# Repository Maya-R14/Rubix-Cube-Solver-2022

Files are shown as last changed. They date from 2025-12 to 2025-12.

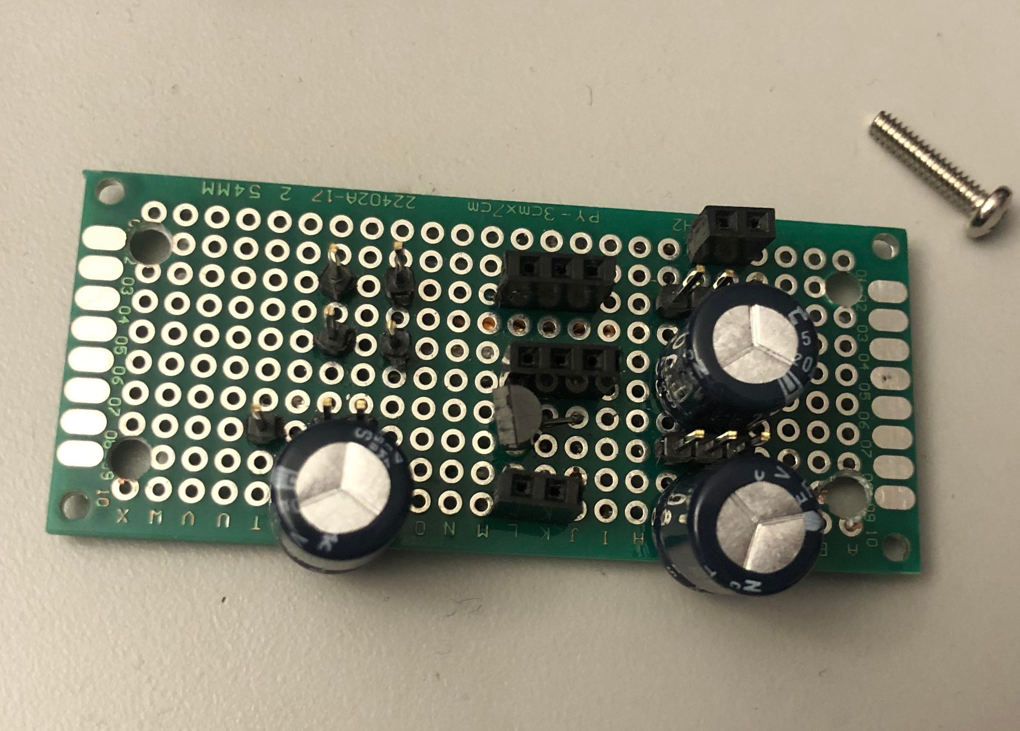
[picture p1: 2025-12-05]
Board and Components/Pinout Board.jpg

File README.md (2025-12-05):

# Rubix-Cube-Solver-2022
## MEDIA 
  Videos seem to be too large for Gethub.
- https://youtube.com/shorts/mSMcaVYMW5o?feature=share
- https://youtube.com/shorts/OSVltd1bibA?feature=share
## Features
- Servo motor–driven arms to manipulate the cube
- Sensor-based color detection for all cube faces
- Algorithm to compute the optimal solution
- Fully automated solving process

## Hardware
- Servo motors for cube manipulation
- Camera module
- Rasberry Pi
- Custom frame to hold cube
- PCB, resistors, capacitors, wires

## Software / Tools
- 3D Modeling/Solidworks
- Soldering
- PuTTY
- Raspberry Pi

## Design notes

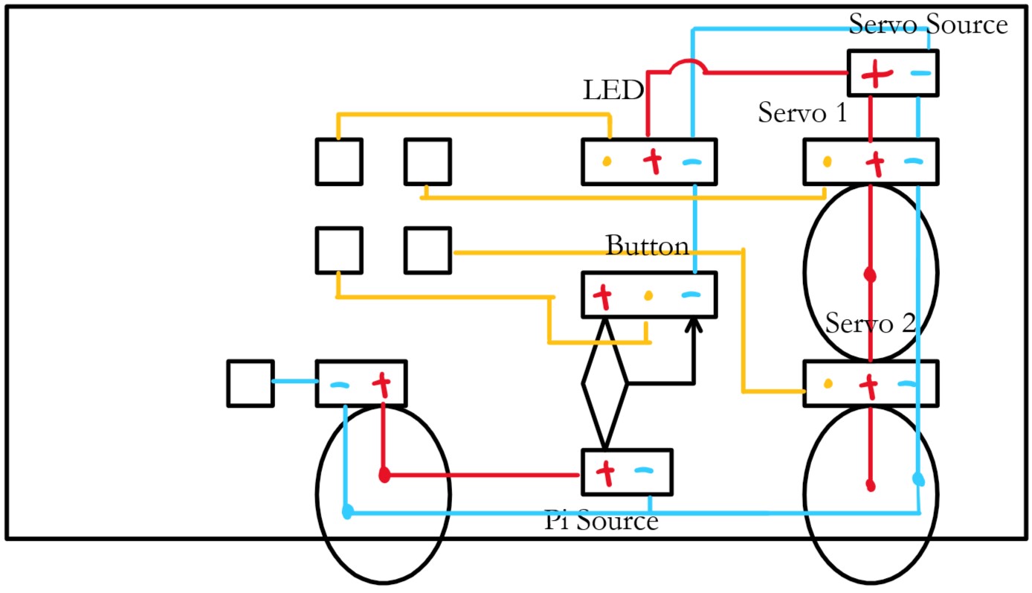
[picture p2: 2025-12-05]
Board and Components/Pinout Board Diagram.jpg

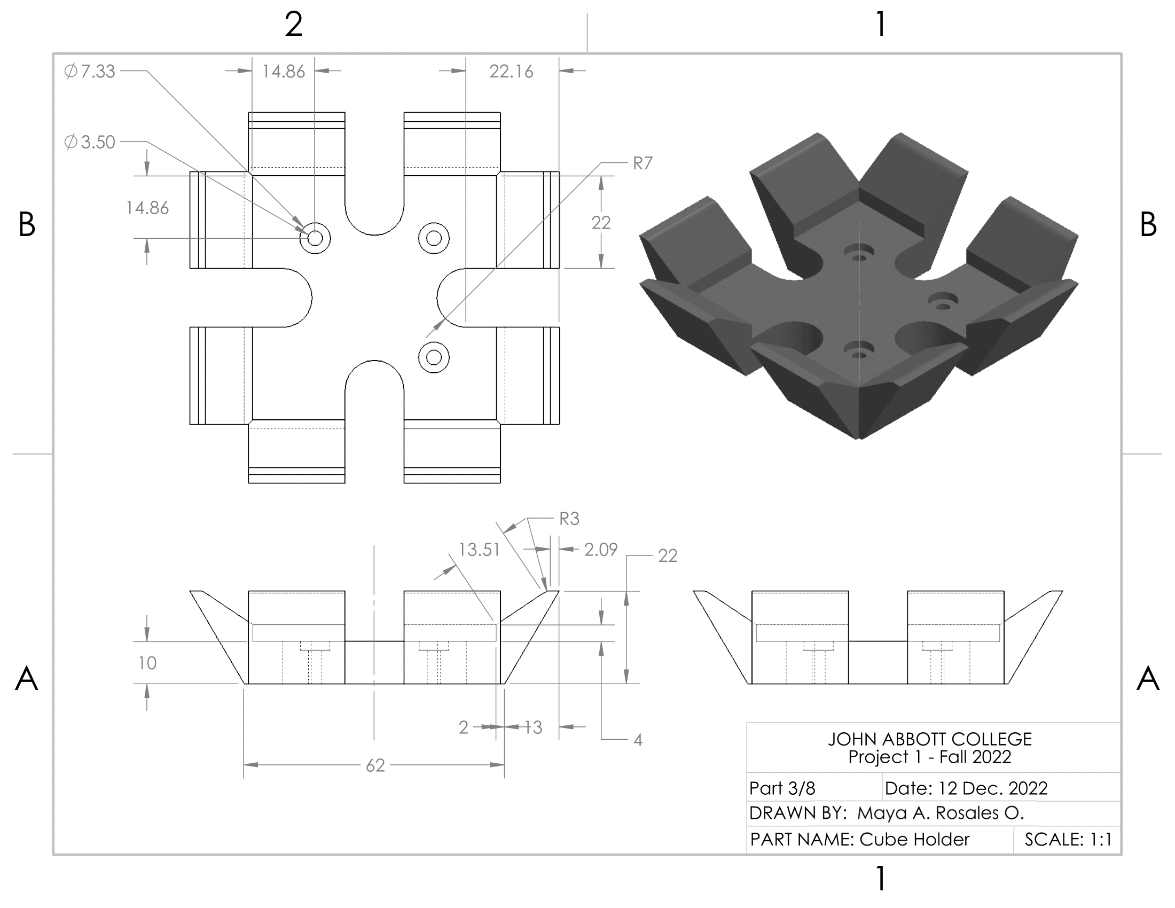
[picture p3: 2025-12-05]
3D Modeling/Technical Drawings/PNGs/Maya A. Rosales O._Solver_Technical Sheet-3.png

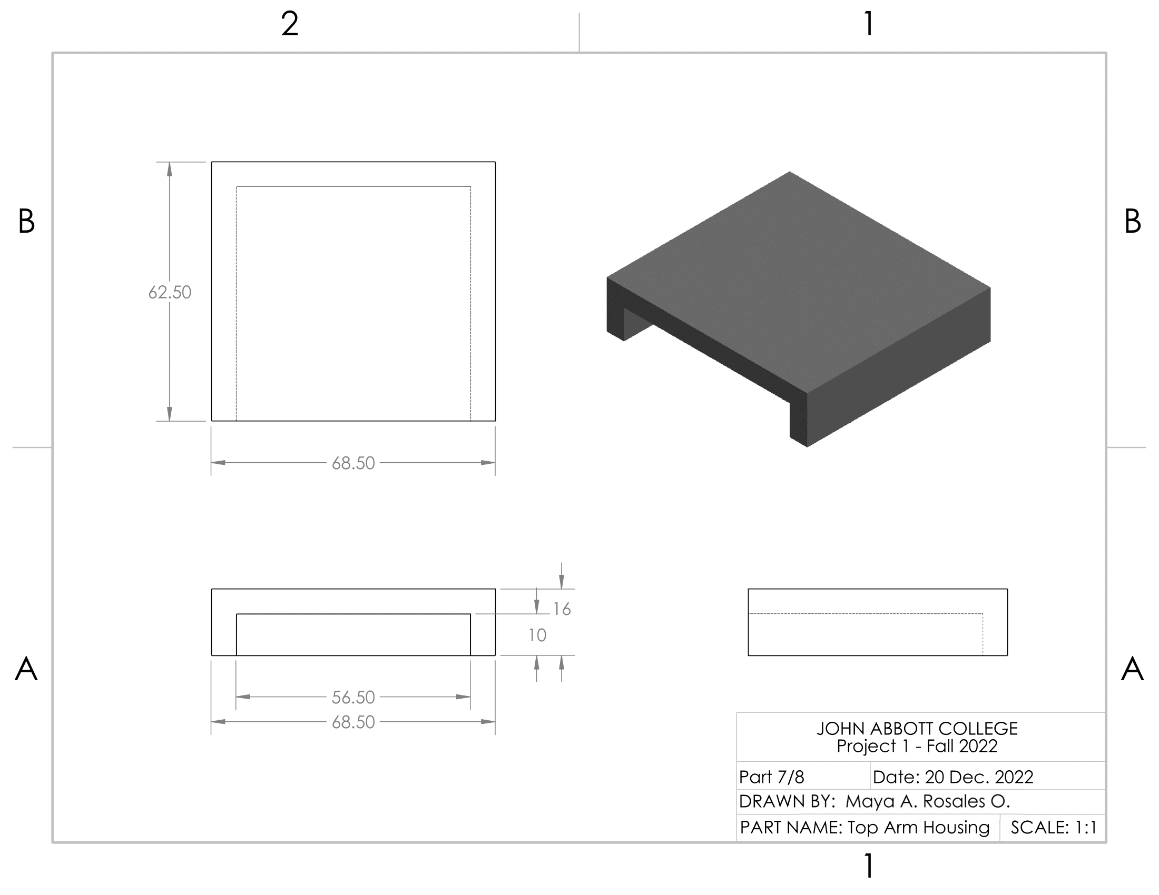
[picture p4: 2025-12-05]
3D Modeling/Technical Drawings/PNGs/Maya A. Rosales O._Solver_Technical Sheet-7.png

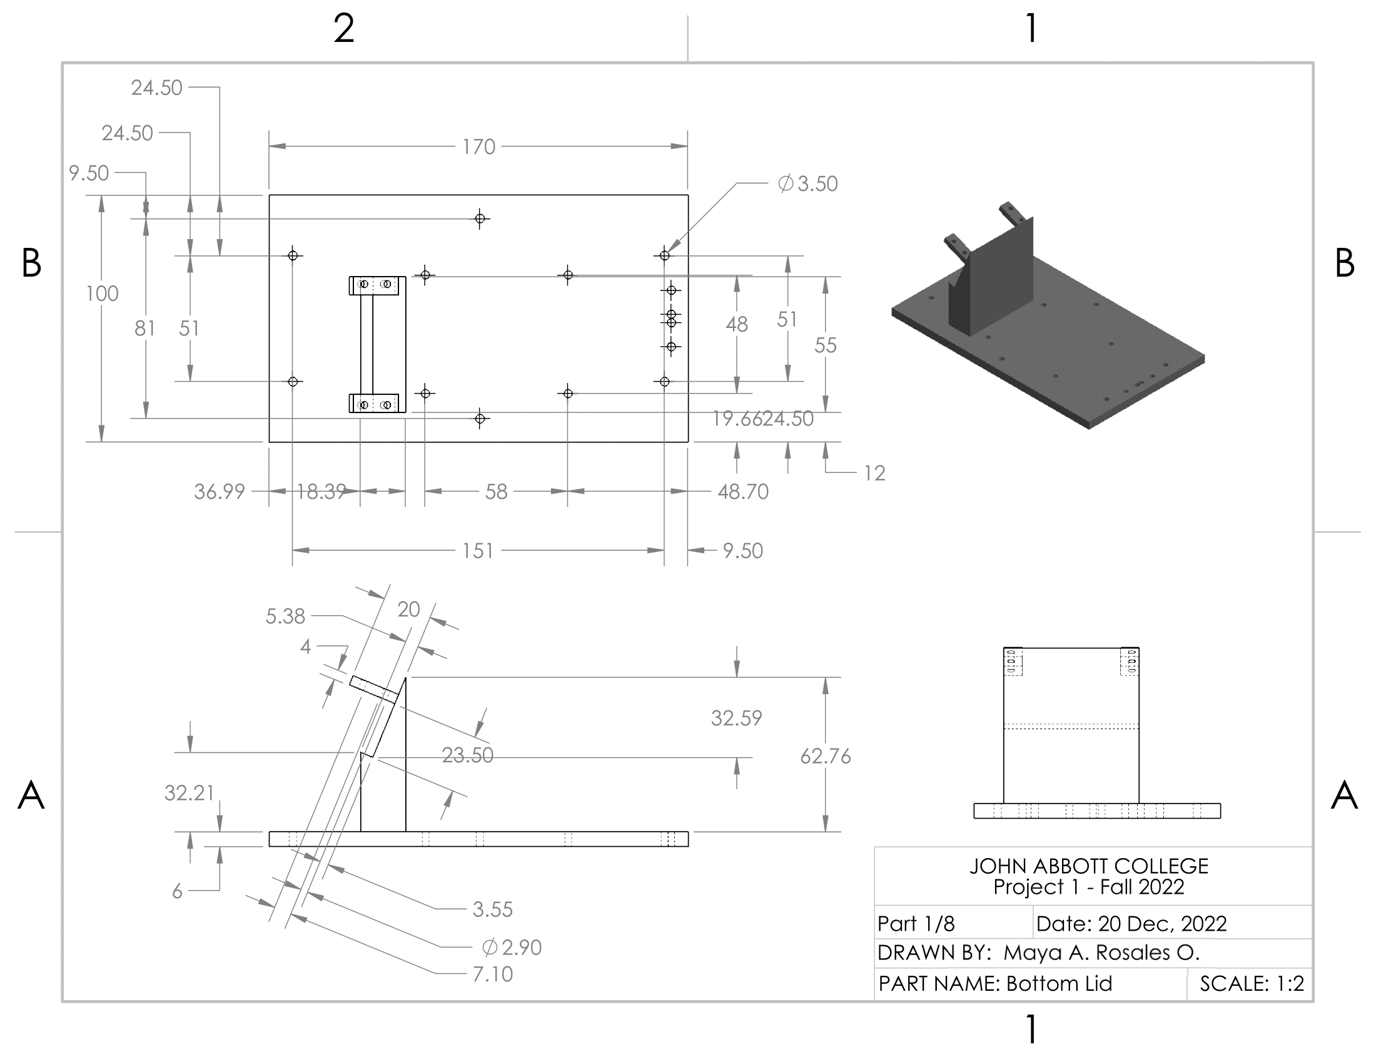
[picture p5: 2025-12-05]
3D Modeling/Technical Drawings/PNGs/Maya A. Rosales O._Solver_Technical Sheet-1.png

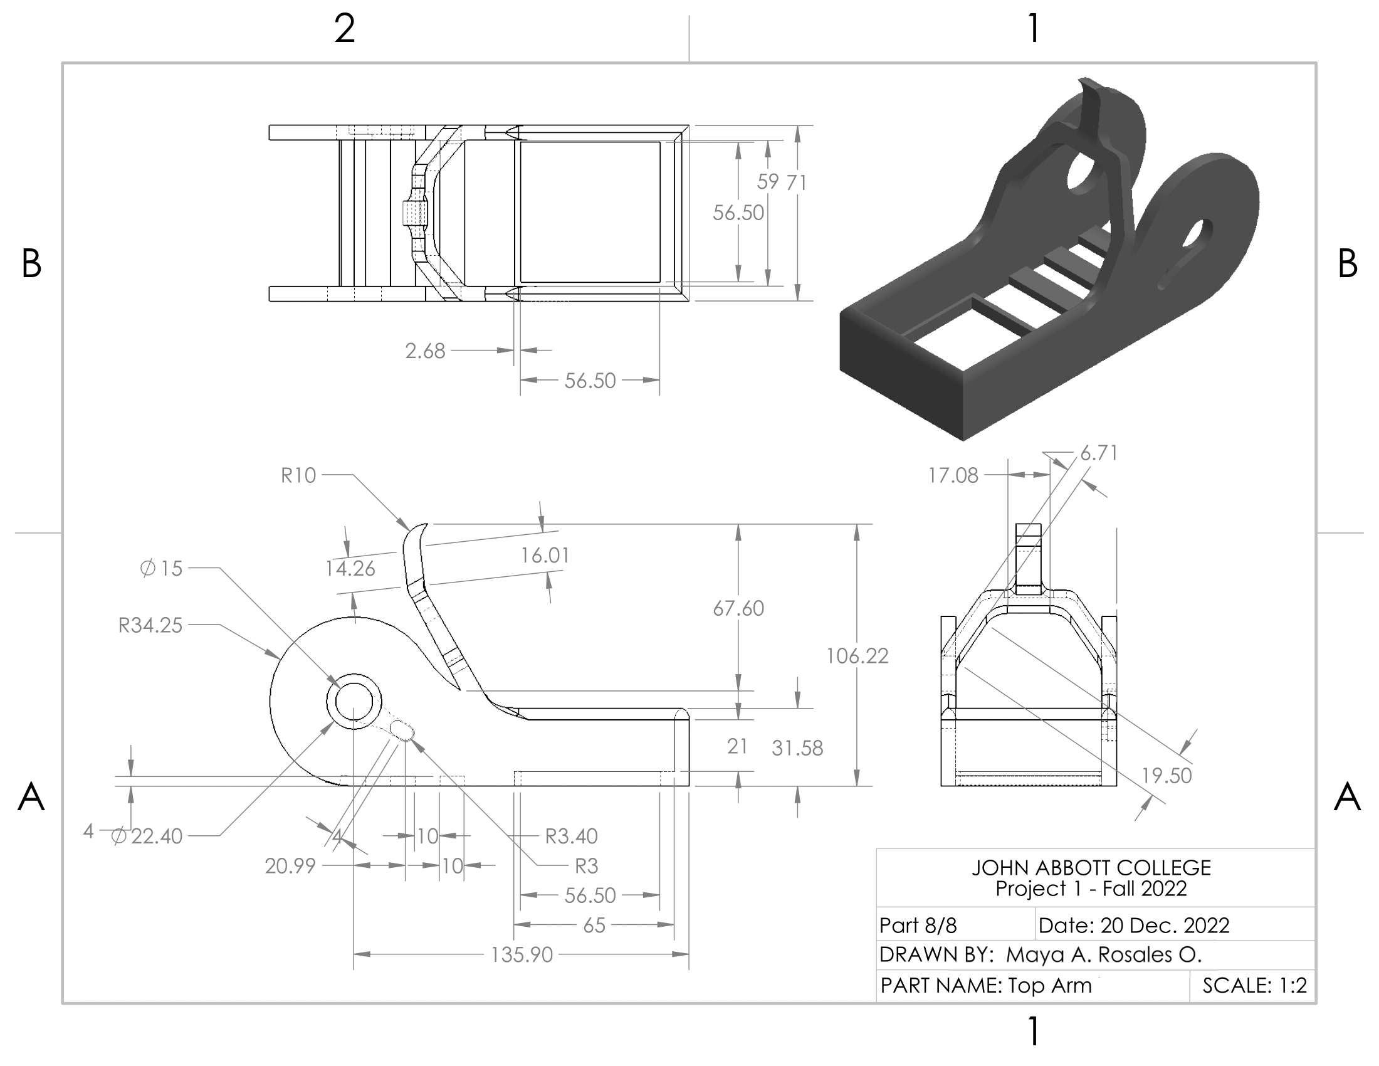
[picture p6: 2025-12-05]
3D Modeling/Technical Drawings/PNGs/Maya A. Rosales O._Solver_Technical Sheet-8.png

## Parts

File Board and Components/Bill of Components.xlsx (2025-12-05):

Amount | Item | Acquiring Method | Cost Per Unit | Total Cost
1 | Rasperry Pi 3B | Second Hand | $0.00 | $0.00
2 | 270 Degrees servo Motor | Bought at ABRA | $24.95 | $49.90
1 | Capacitive Touch Sensor | Bought at ABRA | $1.49 | $1.49
1 | 3W LED | Bought at ABRA | $3.37 | $3.37
2 | Micro USB breakout Board | Bought at ABRA | $1.68 | $3.36
1 | Pi Camera 1.3V | Bought at Amazon | $14.99 | $14.99
1 | FFC Cable | Bought at Amazon | $3.07 | $3.07
1 | LED Indicator | Bought at ABRA | $4.00 | $4.00
1 | L4931 Voltage Regulator | Bought at ABRA | $1.95 | $1.95
1 | 3x7 Printed Circuit | Bought at ABRA | $1.92 | $1.92
3 | Capacitors 35V, 220uF | Provided By JAC | $0.00 | $0.00
2 | Header Set | Bought at ABRA | $1.07 | $2.14
N/A | 3D Printing Material | Provided By JAC | $0.00 | $0.00
29 | 4-40 screws (various lengths) | Provided By JAC | $0.00 | $0.00
17 | 4-40 Bolts | Provided By JAC | $0.00 | $0.00
 |  |  | Total | $86.19
 |  |  | Total + Tax | $99.12

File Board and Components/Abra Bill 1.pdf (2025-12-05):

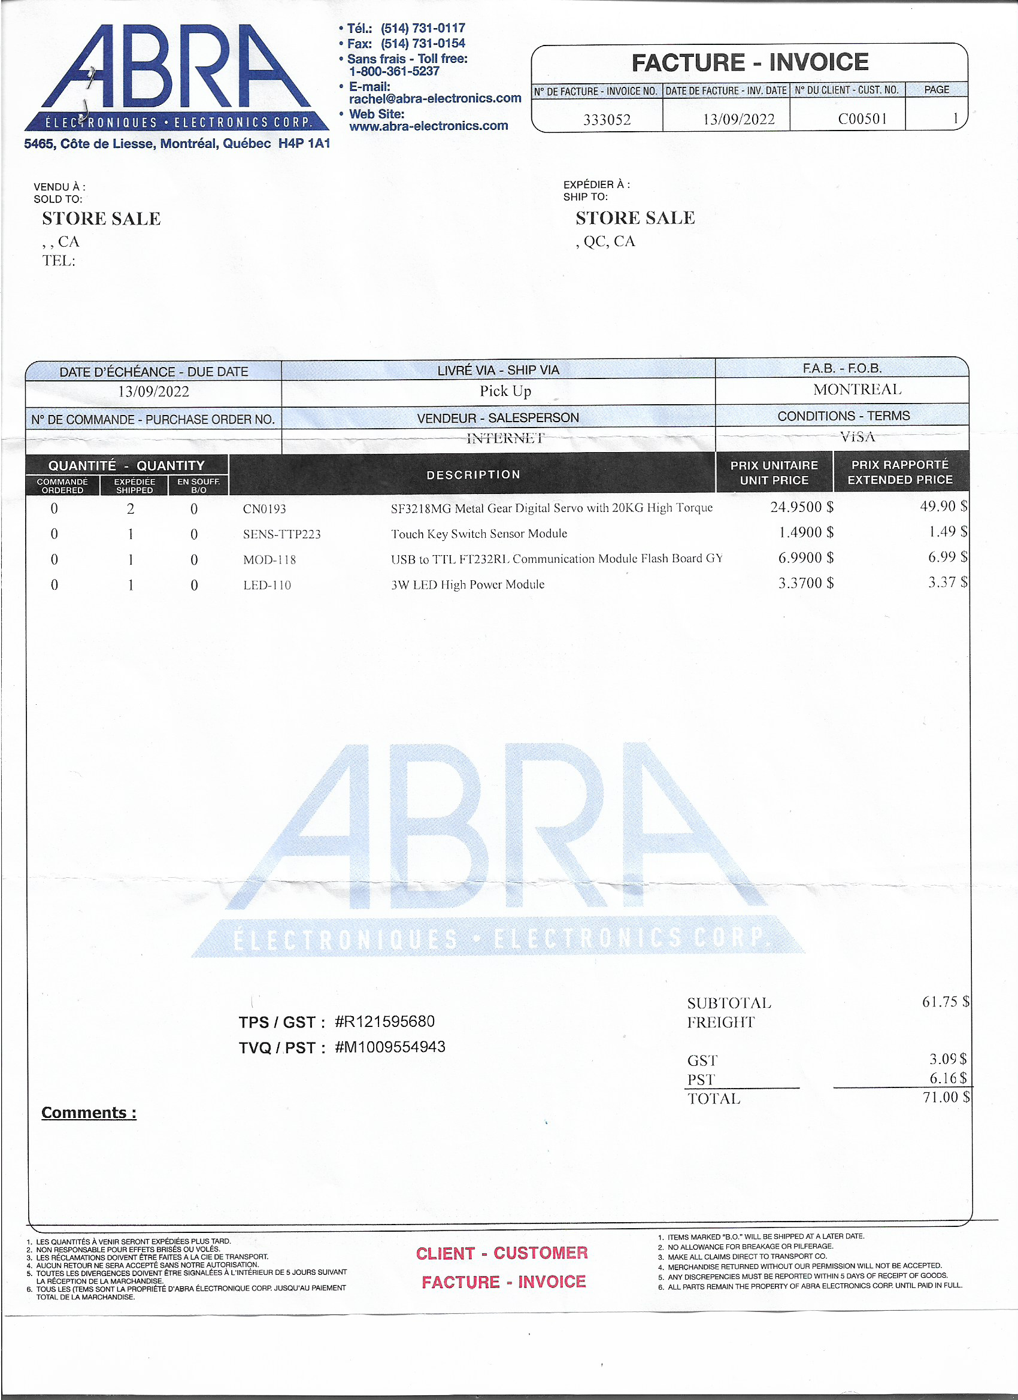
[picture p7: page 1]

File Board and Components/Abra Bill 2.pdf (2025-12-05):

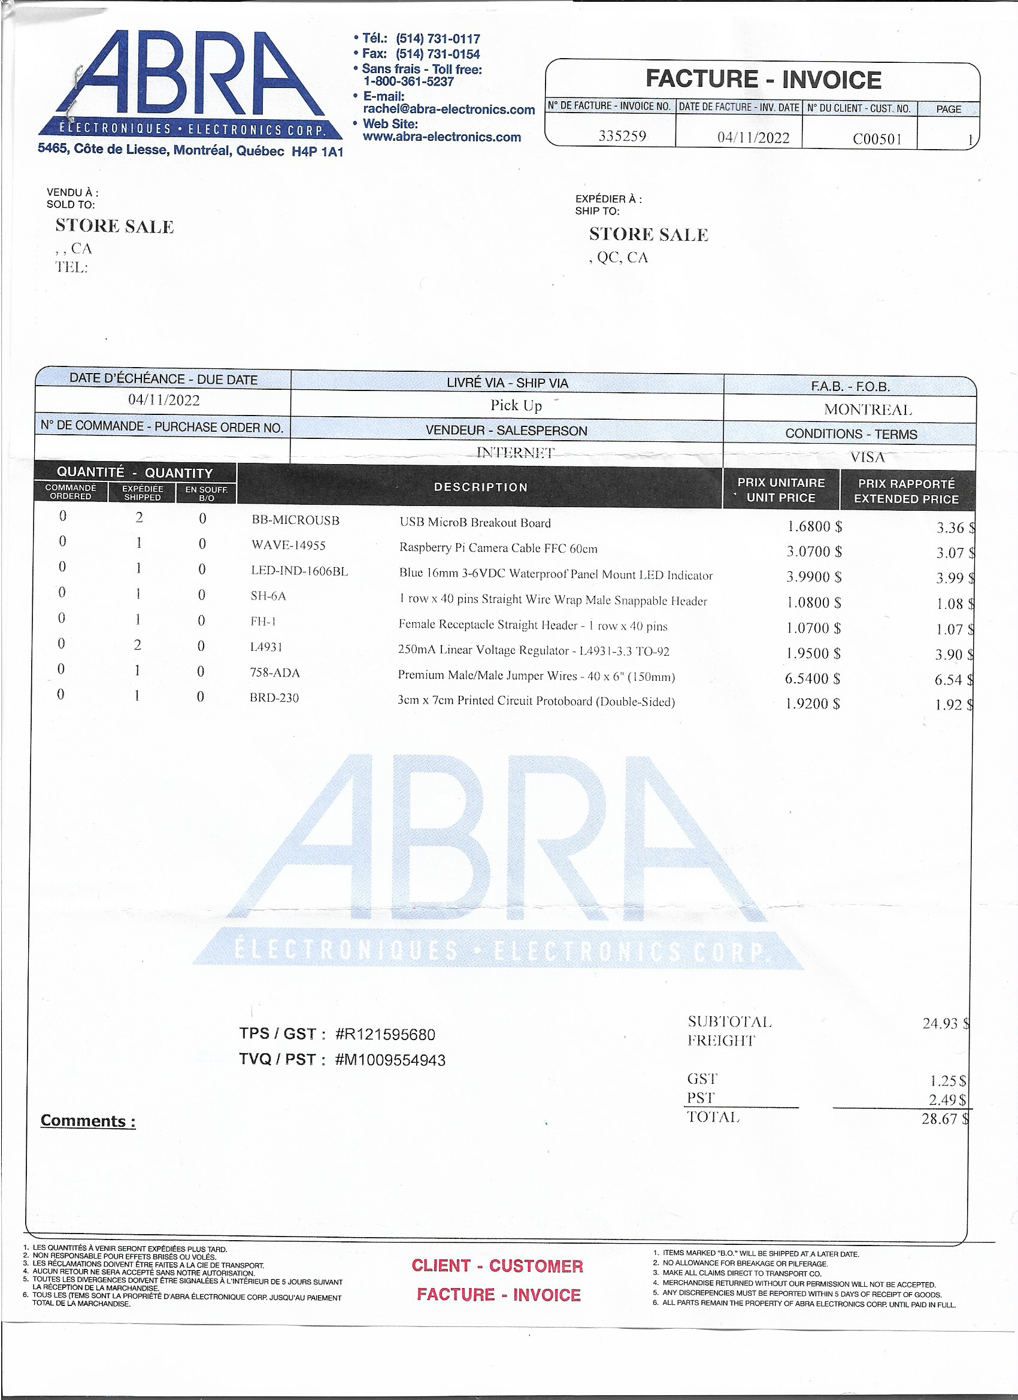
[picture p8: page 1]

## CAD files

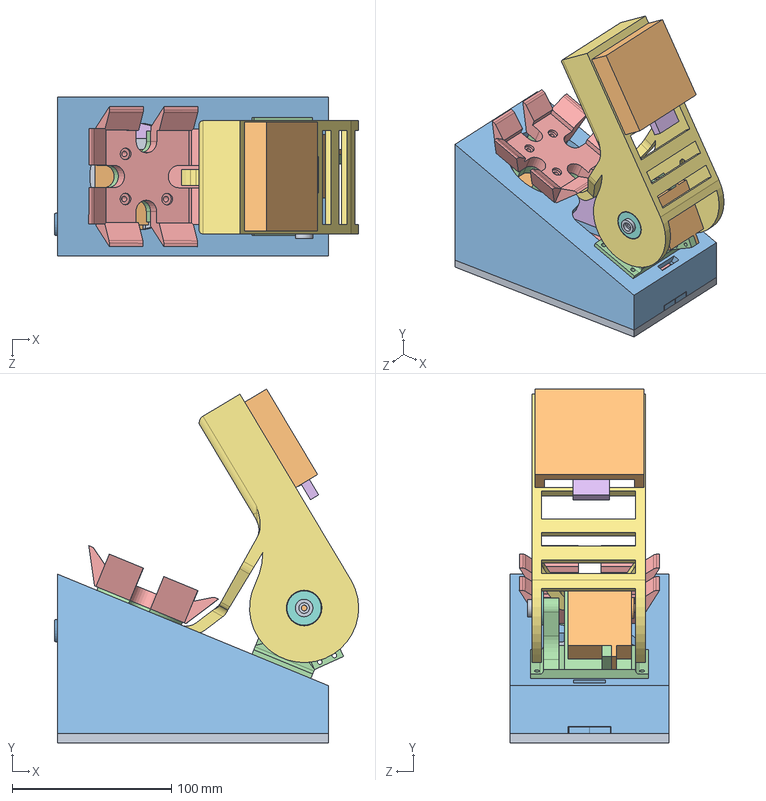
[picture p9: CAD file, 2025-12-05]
3D Modeling/Rubix Cube Solver Assembly.SLDASM
191.0 x 222.2 x 100.0 mm
Part - Bottom Lid
REFERENCE - Motor x 2
Part - Casing
Part - Hinge
REFERENCE - PI
REFERENCE - Connection Board
Part - Top Arm
REFERENCE - Ball Bearing
Part - Hinge - Screw
Part - Top Arm - Camera Housing
REFERENCE - Charging Board x 2
Part - Rotary Disk
Part - Cube Holder
REFERENCE - LED
REFERENCE - Pi Camera

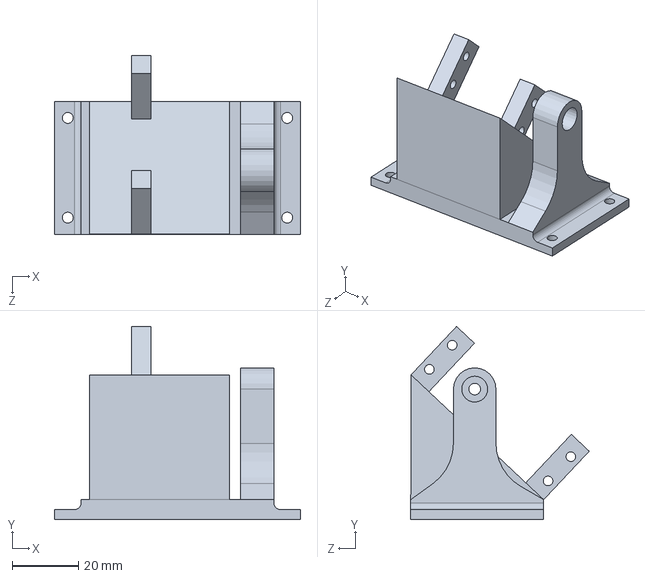
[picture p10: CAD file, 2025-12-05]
3D Modeling/Parts/Part - Hinge.SLDPRT
74.0 x 58.1 x 53.7 mm

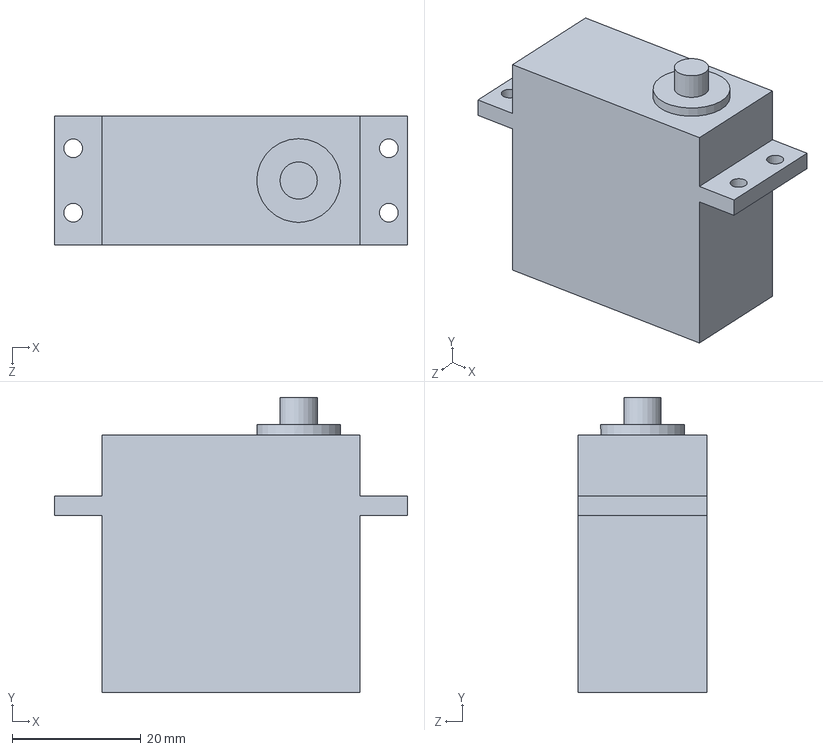
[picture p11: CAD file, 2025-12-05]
3D Modeling/References/REFERENCE - Motor.SLDPRT
54.8 x 45.8 x 20.0 mm

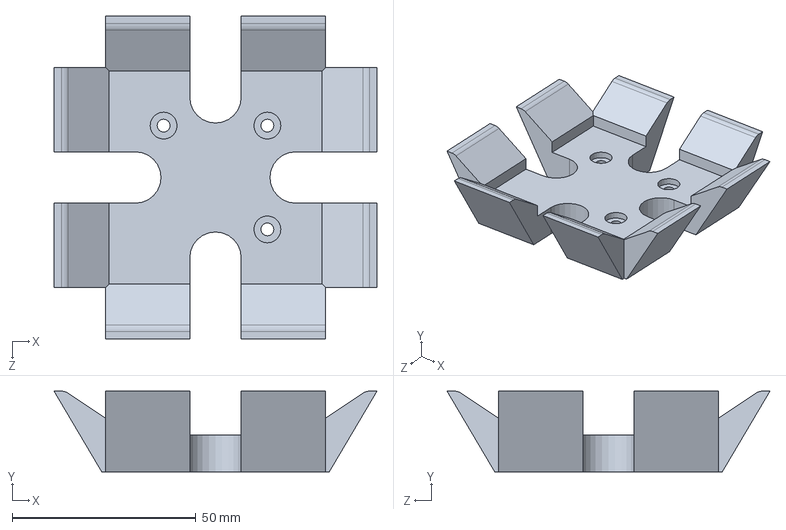
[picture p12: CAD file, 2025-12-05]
3D Modeling/Parts/Part - Cube Holder.SLDPRT
88.0 x 22.0 x 88.0 mm

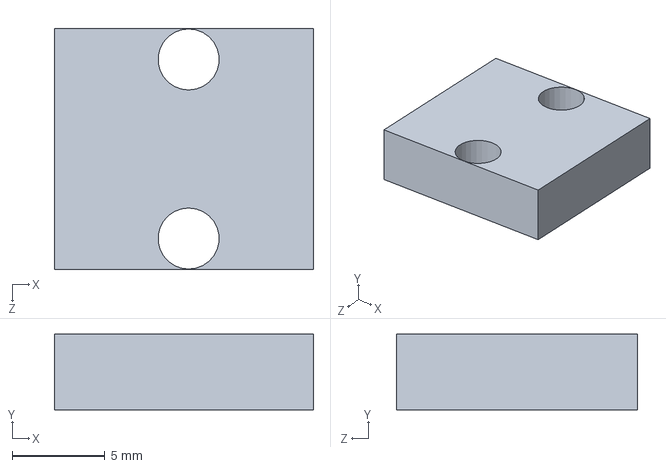
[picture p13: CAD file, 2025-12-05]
3D Modeling/References/REFERENCE - Charging Board.SLDPRT
14.0 x 4.10 x 13.0 mm

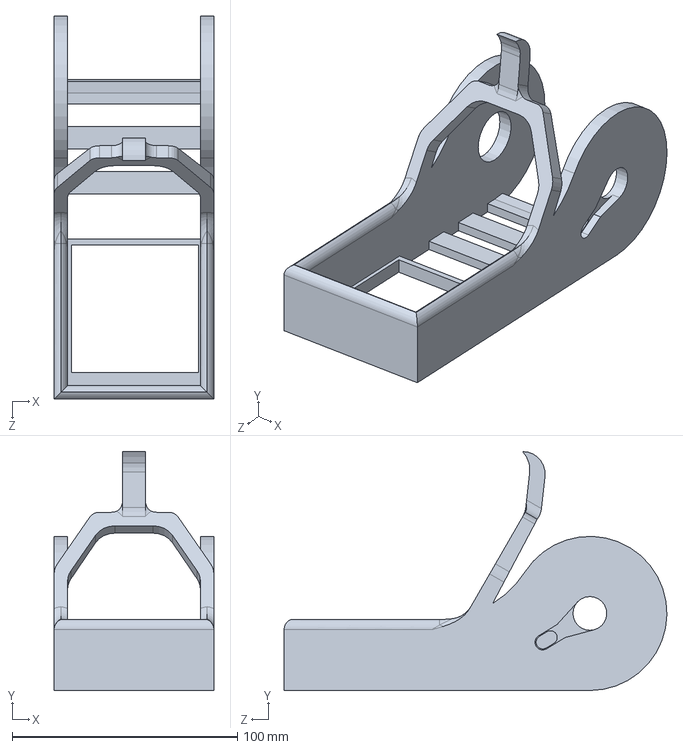
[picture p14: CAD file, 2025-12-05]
3D Modeling/Parts/Part - Top Arm.SLDPRT
71.0 x 106.2 x 170.1 mm

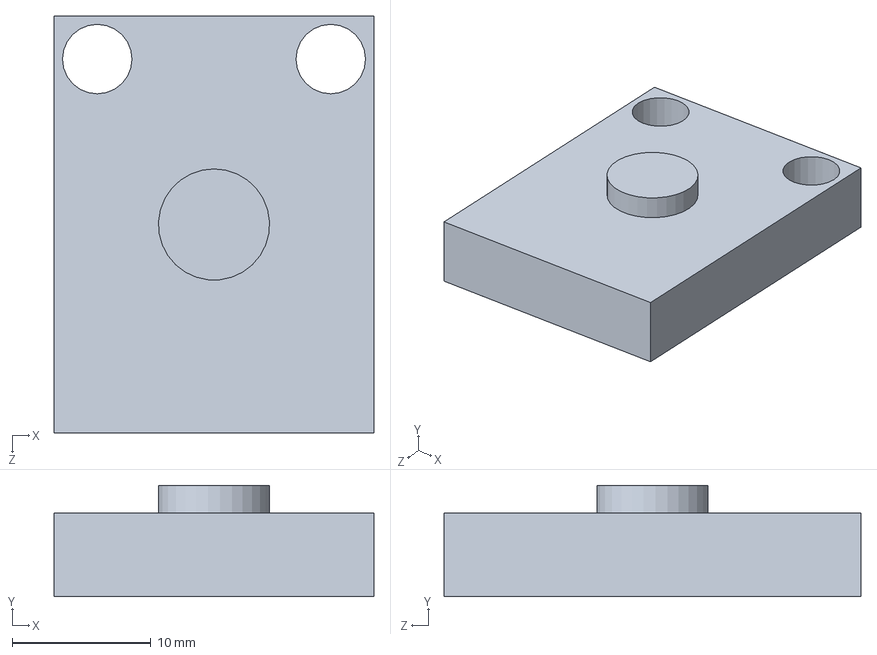
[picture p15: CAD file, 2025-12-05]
3D Modeling/References/REFERENCE - LED.SLDPRT
23.0 x 8.00 x 30.0 mm

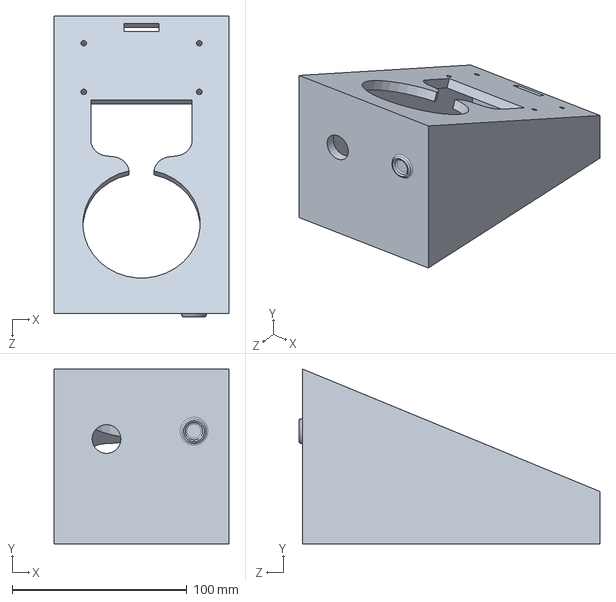
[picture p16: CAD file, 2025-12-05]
3D Modeling/Parts/Part - Casing.SLDPRT
100.0 x 100.0 x 172.0 mm

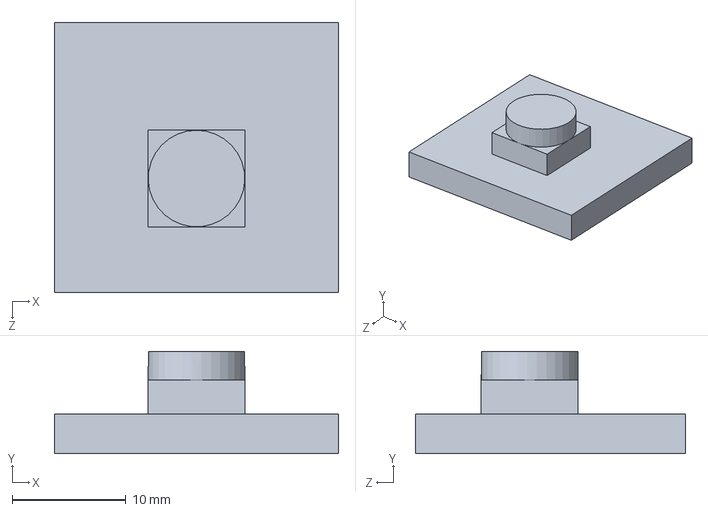
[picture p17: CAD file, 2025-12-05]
3D Modeling/References/REFERENCE - Pi Camera.SLDPRT
25.0 x 9.00 x 23.8 mm

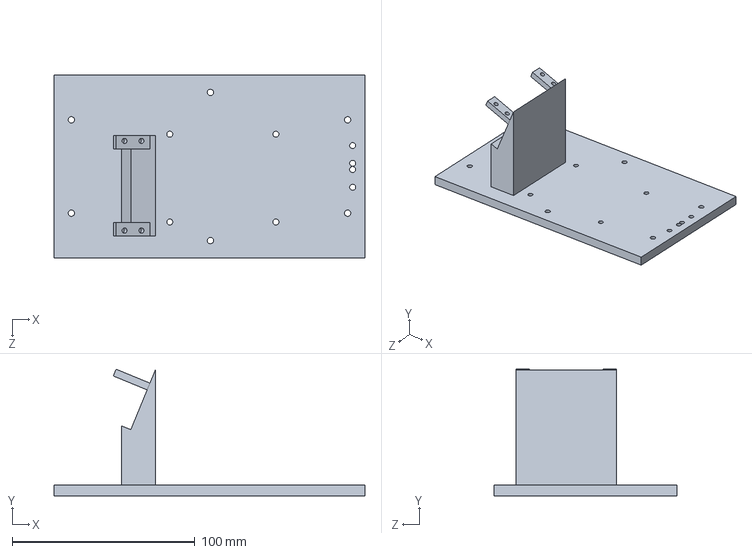
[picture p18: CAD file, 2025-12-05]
3D Modeling/Parts/Part - Bottom Lid.SLDPRT
170.0 x 69.2 x 100.0 mm

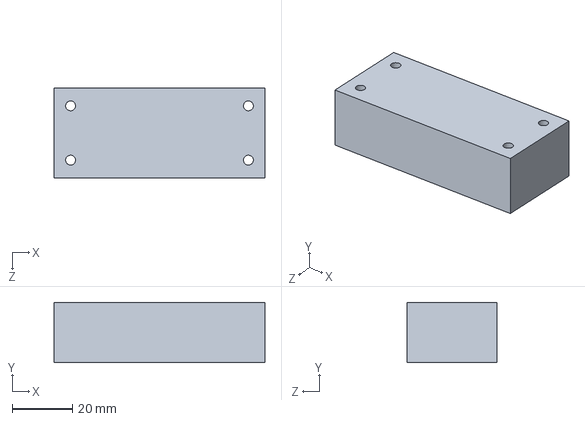
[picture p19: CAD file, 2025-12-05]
3D Modeling/References/REFERENCE - Connection Board.SLDPRT
70.0 x 20.0 x 30.0 mm

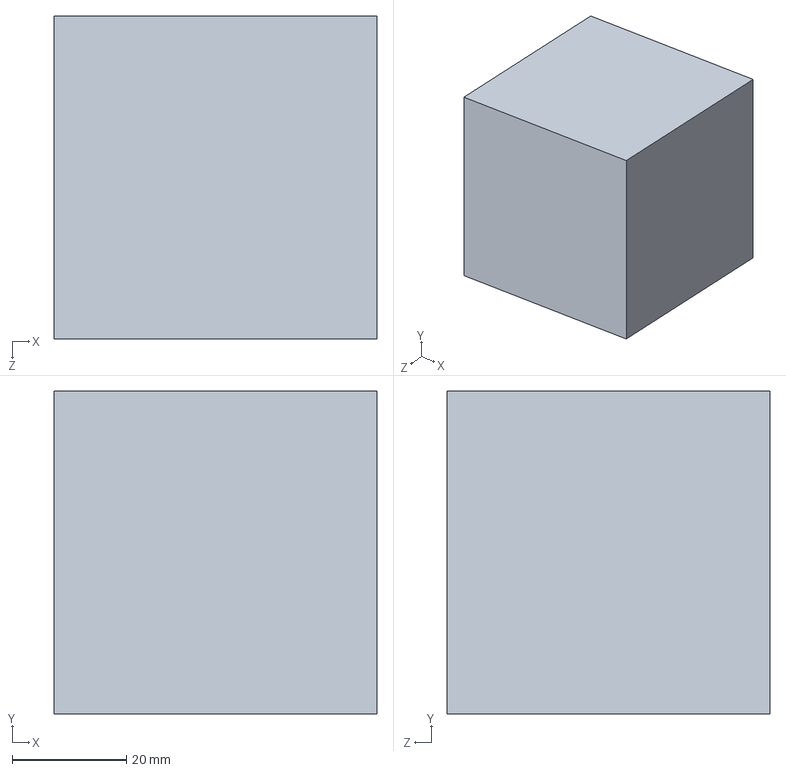
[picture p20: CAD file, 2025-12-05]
3D Modeling/References/REFERENCE - Rubix Cube.SLDPRT
56.5 x 56.5 x 56.5 mm

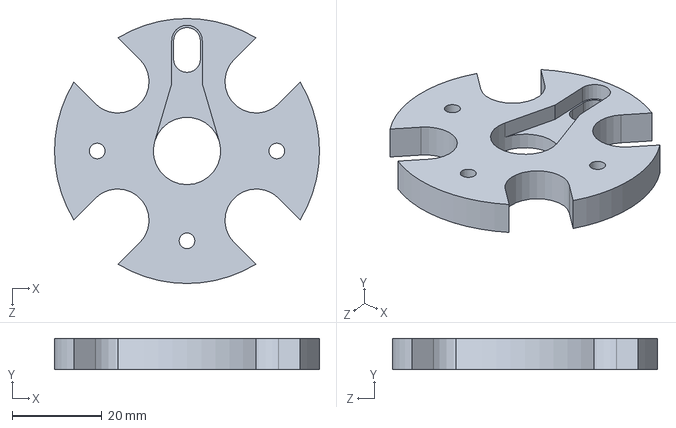
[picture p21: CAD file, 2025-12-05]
3D Modeling/Parts/Part - Rotary Disk.SLDPRT
59.0 x 7.00 x 59.0 mm

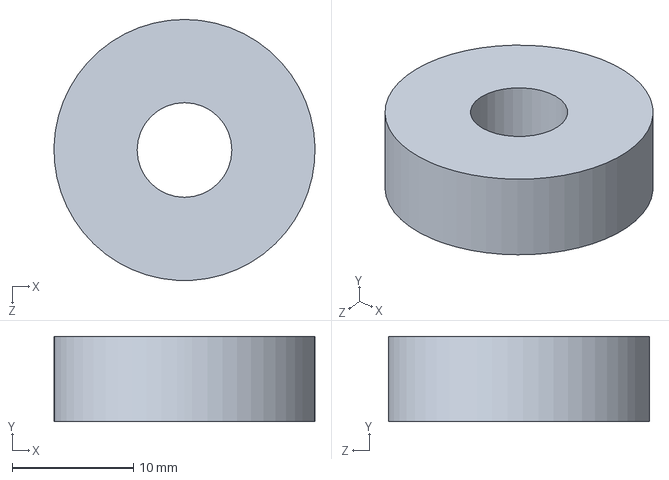
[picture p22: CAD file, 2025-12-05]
3D Modeling/References/REFERENCE - Ball Bearing.SLDPRT
21.5 x 7.00 x 21.5 mm

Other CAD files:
3D Modeling/Parts/Part - Top Arm - Camera Housing.SLDPRT
3D Modeling/References/REFERENCE - PI.SLDPRT
3D Modeling/Parts/Part - Hinge - Screw.SLDPRT
3D Modeling/STL Files (Printable)/Part - Bottom Lid.STL
3D Modeling/STL Files (Printable)/Part - Casing.STL
3D Modeling/STL Files (Printable)/Part - Cube Holder.STL
3D Modeling/STL Files (Printable)/Part - Hinge - Screw.STL
3D Modeling/STL Files (Printable)/Part - Hinge.STL
3D Modeling/STL Files (Printable)/Part - Rotary Disk.STL
3D Modeling/STL Files (Printable)/Part - Top Arm - Camera Housing.STL
3D Modeling/STL Files (Printable)/Part - Top Arm.STL
3D Modeling/Technical Drawings/Drawings/Drawing - Bottom Lid.SLDDRW
3D Modeling/Technical Drawings/Drawings/Drawing - Casing.SLDDRW
3D Modeling/Technical Drawings/Drawings/Drawing - Cube Holder.SLDDRW
3D Modeling/Technical Drawings/Drawings/Drawing - Hinge Screw.SLDDRW
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

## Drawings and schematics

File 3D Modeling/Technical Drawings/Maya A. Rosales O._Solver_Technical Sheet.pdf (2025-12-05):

B

B

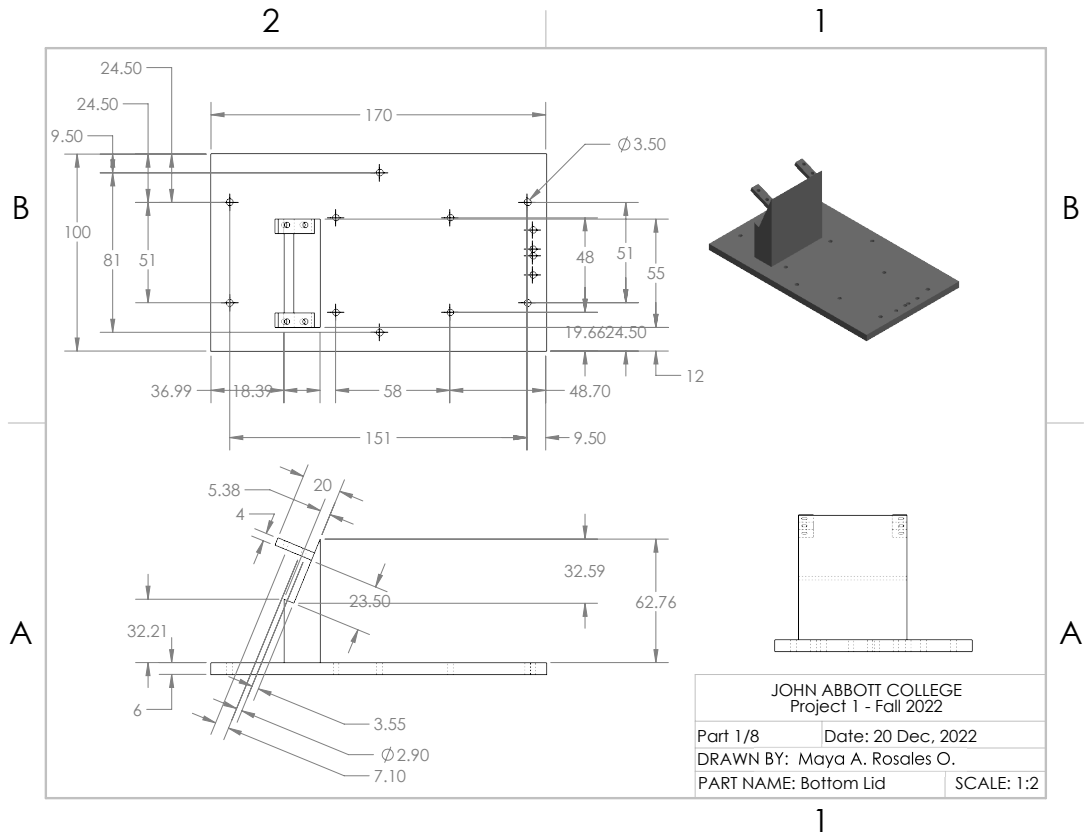
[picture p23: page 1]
Part 1/8; Date: 20 Dec, 2022; PART NAME: Bottom Lid; SCALE: 1:2

JOHN ABBOTT COLLEGE
Project 1 - Fall 2022

DRAWN BY: Marco A. Rosales O.

B

B

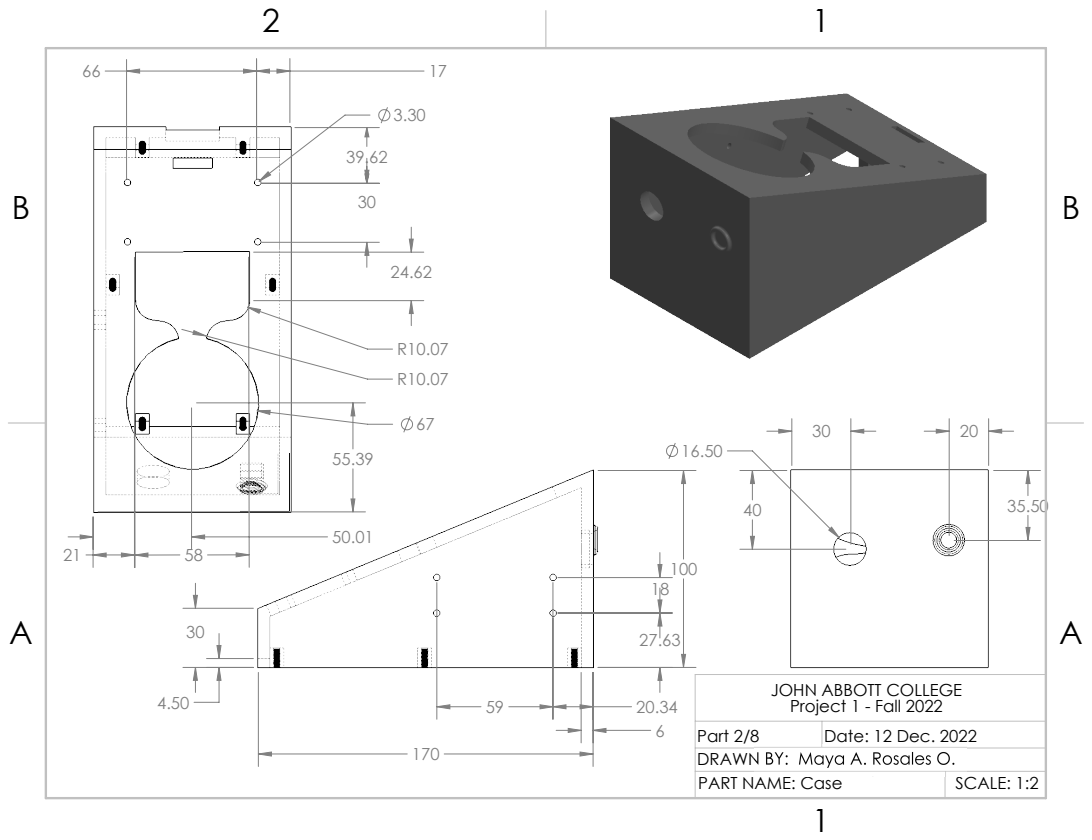
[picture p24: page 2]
Part 2/8; Date: 12 Dec. 2022; DRAWN BY: Marco A. Rosales O.; PART NAME: Case; SCALE: 1:2

JOHN ABBOTT COLLEGE
Project 1 - Fall 2022

B

B

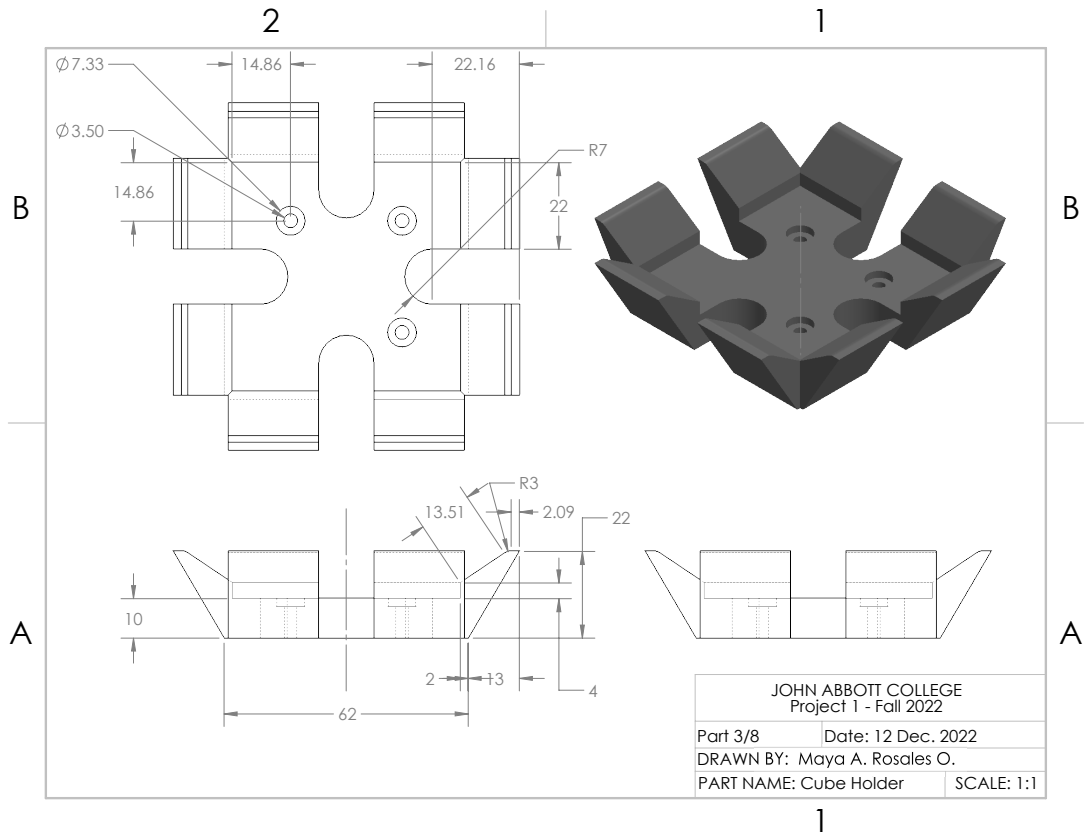
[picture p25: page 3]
Part 3/8; Date: 12 Dec. 2022; PART NAME: Cube Holder; SCALE: 1:1

JOHN ABBOTT COLLEGE
Project 1 - Fall 2022

DRAWN BY: Marco A. Rosales O.

B

B

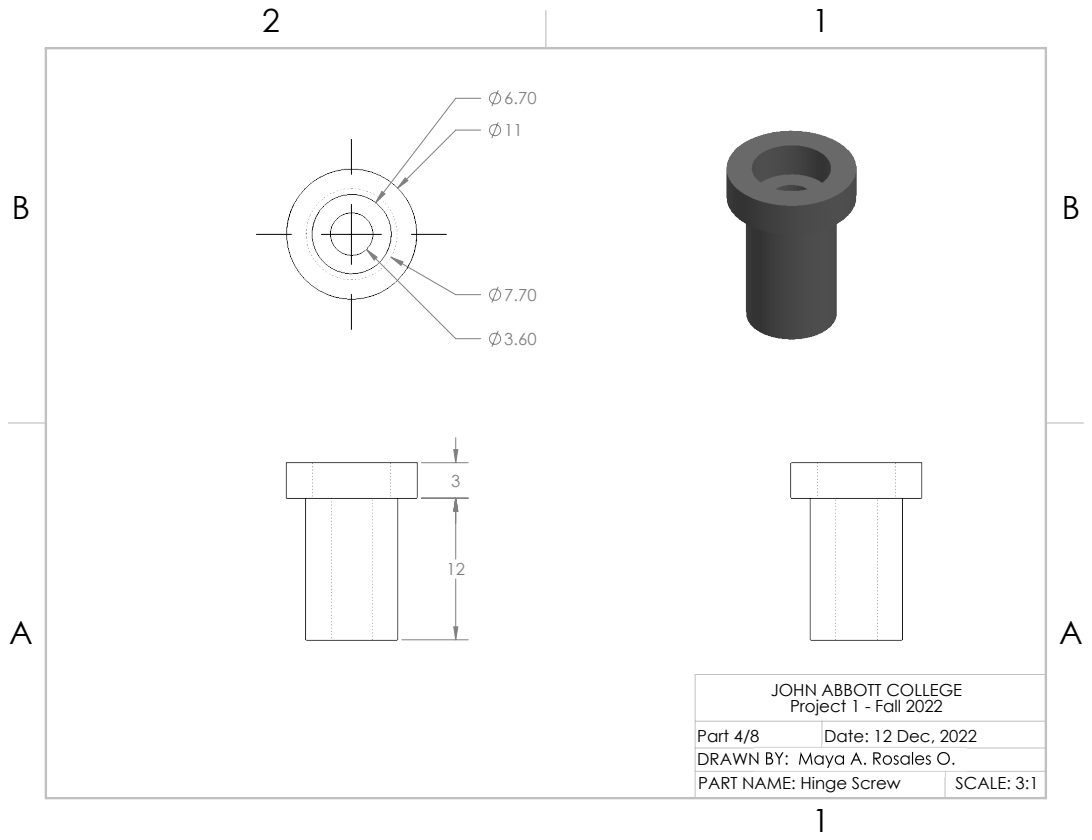
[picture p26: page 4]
Part 4/8; Date: 12 Dec, 2022; PART NAME: Hinge Screw; SCALE: 3:1

JOHN ABBOTT COLLEGE
Project 1 - Fall 2022

DRAWN BY: Marco A. Rosales O.

B

B

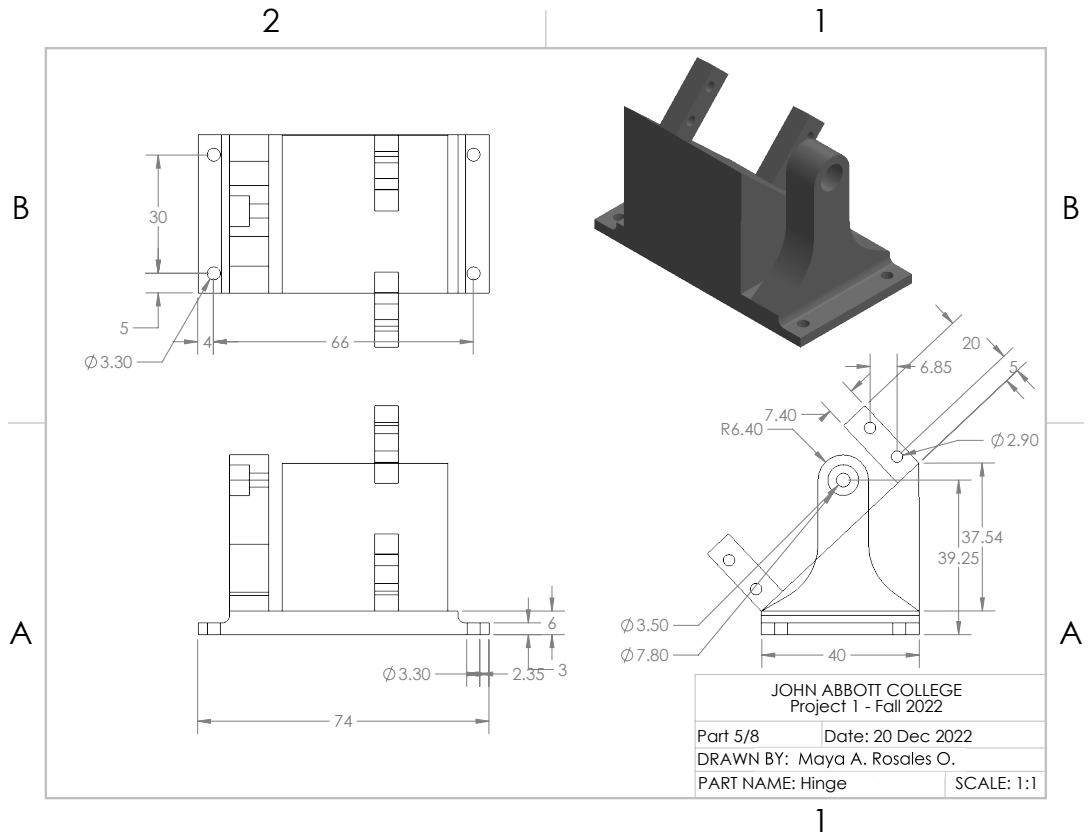
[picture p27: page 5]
Part 5/8; Date: 20 Dec 2022; PART NAME: Hinge; SCALE: 1:1

JOHN ABBOTT COLLEGE
Project 1 - Fall 2022

DRAWN BY: Marco A. Rosales O.

B

B

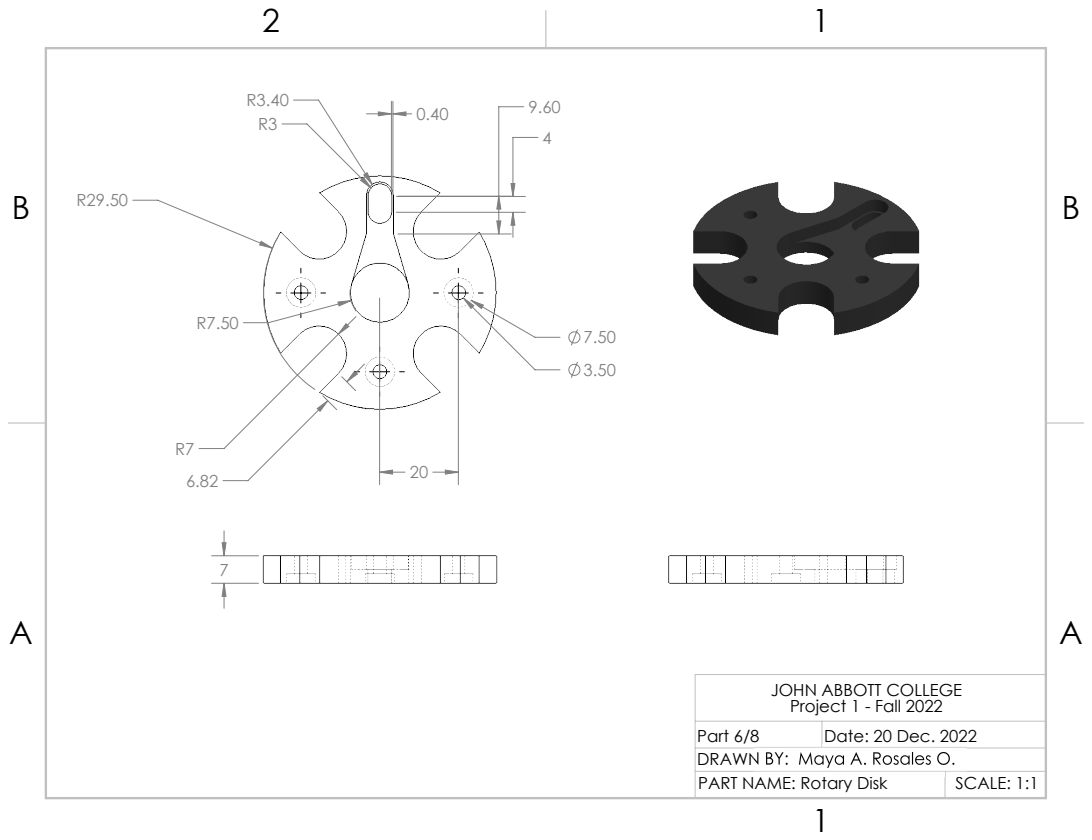
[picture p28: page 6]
Part 6/8; Date: 20 Dec. 2022; PART NAME: Rotary Disk; SCALE: 1:1

JOHN ABBOTT COLLEGE
Project 1 - Fall 2022

DRAWN BY: Marco A. Rosales O.

B

B

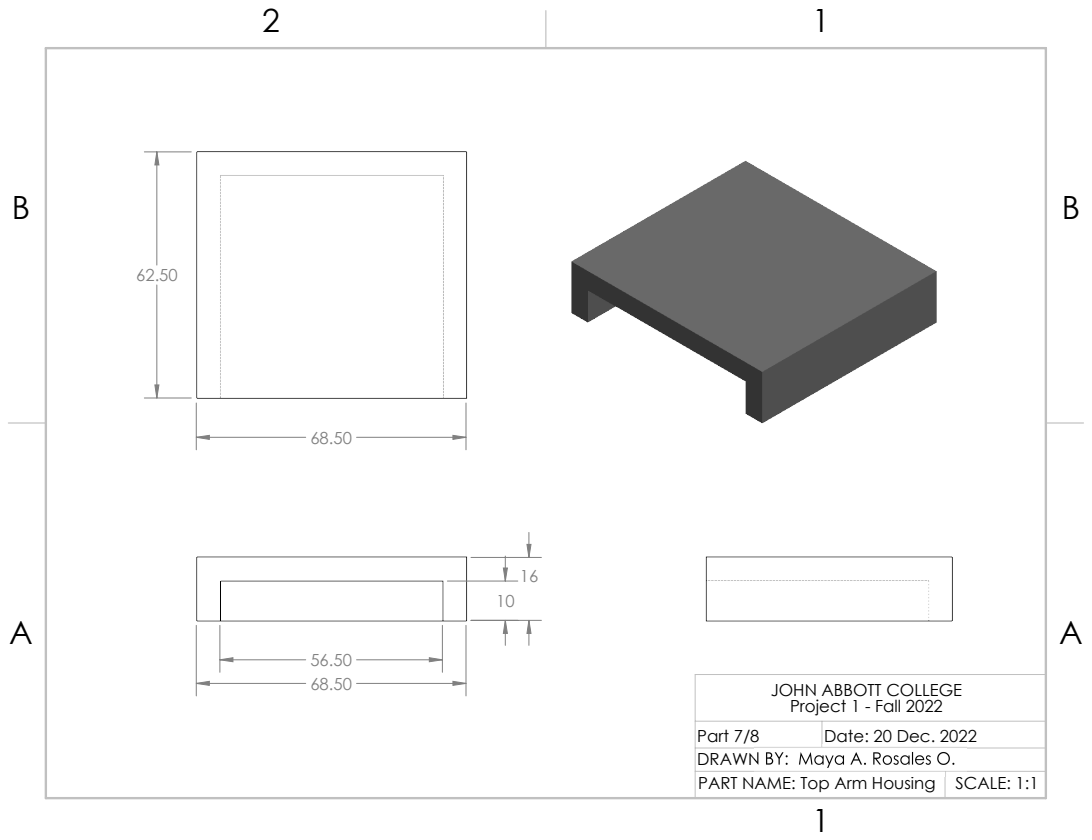
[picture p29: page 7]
Part 7/8; Date: 20 Dec. 2022; PART NAME: Top Arm Housing; SCALE: 1:1

JOHN ABBOTT COLLEGE
Project 1 - Fall 2022

DRAWN BY: Marco A. Rosales O

B

B

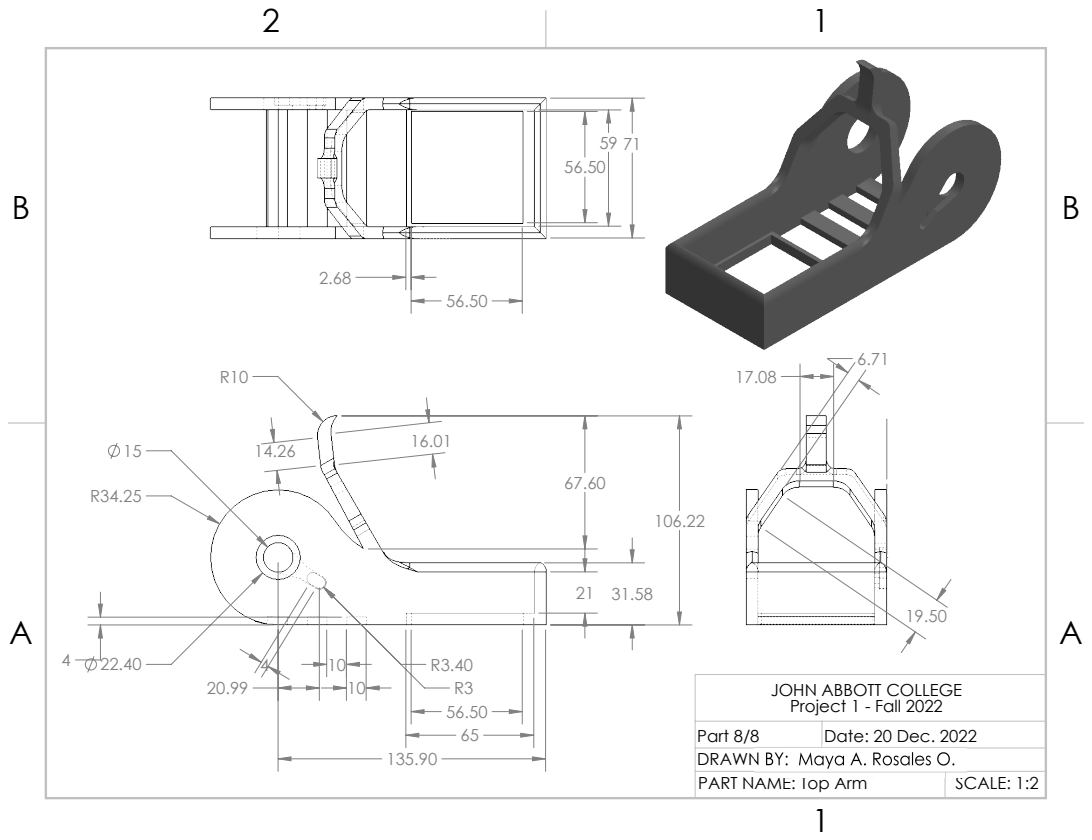
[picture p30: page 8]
Part 8/8; Date: 20 Dec. 2022; PART NAME: Top Arm; SCALE: 1:2

JOHN ABBOTT COLLEGE
Project 1 - Fall 2022

DRAWN BY: Marco A. Rosales O.

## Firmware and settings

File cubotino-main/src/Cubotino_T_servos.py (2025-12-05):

#!/usr/bin/python
# coding: utf-8

"""
#############################################################################################################
# This specific script controls two servos based on the movements string from Cubotino.py
# 
# Possible moves with this robot
# 1) Spins the complete cube ("S") laying on the bottom face: 1 means CW 90deg turns, while 3 means 90CCW turn
# 2) Flips the complete cube ("F") by "moving" the Front face to Bottom face: Only positive values are possible
# 3) Rotates the bottom layer ("R") while costraining the 2nd and 3rd layer.
# 4) The order of S, F has to be strictly followed
# 5) Example 'F1R1S3' means: 1x cube Flip, 1x (90deg) CW rotation of the 1st (Down) layer, 1x (90deg) CCW cube Spin
#
# For Rotations, the bottom servo makes a little extra rotation than target, before coming back to target; This
# is needed to recover the gaps between cube_hoder - cube - top_cover, and still getting a decent cube layers alignment.

#############################################################################################################
"""

##################    imports for the display part   ################################
from Cubotino_T_display import display as s_disp
s_disp.set_backlight(0)                           # display backlight is set off
s_disp.show_cubotino()      # show cubotino logo on display, when this script is imported
s_disp.set_backlight(1)                             # activates the display backlight
# ##################################################################################





##################    imports and servo_settings for Servos and LED   ####################
import time                                       # import time library
import RPi.GPIO as GPIO                           # import RPi GPIO library
GPIO.setmode(GPIO.BCM)                            # setting GPIO pins as "Broadcom SOC channel" number, these are the numbers after "GPIO"
GPIO.setwarnings(False)                           # setting GPIO to don't return allarms
from gpiozero import Servo, PWMLED                # import modules for the PWM part
from gpiozero.pins.pigpio import PiGPIOFactory    # pigpio library is used, to use hardare timers on PWM (to avoid servo jitter)
factory = PiGPIOFactory()                         # pin factory setting to use hardware timers, to avoid servo jitter


# servo_settings for the led on top cover, to ensure sufficient light while the PiCamera is reading
top_cover_led_pin = 18                            # GPIO pin used to control the LED on/off/intensity
# NOTE: High frequency on the led PWM is needed to prevent the camera to see the led flickering
top_cover_led = PWMLED(top_cover_led_pin, active_high=True, initial_value=0, frequency=5000000, pin_factory=factory)

# overall servo_settings for the GPIO and the PWM
t_servo_pin = 12                  # GPIO pin used for the top servo
b_servo_pin = 13                  # GPIO pin used for the bottom servo
# ##################################################################################



##################    general servo_settings    #########################################
robot_init_status=False         # boolean to track the servos inititialization status
stop_servos=True                # boolean to stop the servos during solving proces: It is set true at the start, servos cannot operate
b_servo_operable=False          # variable to block/allow bottom servo operation
fun_status=False                # boolean to track the robot fun status, it is True after solving the cube :-)
s_debug=False                   # boolean to print out info when debugging
# ##################################################################################




def init_servo(print_out=s_debug, home_pos=True):
    """ Function to initialize the robot (servos position) and some global variables, do be called once, at the start.
        Parameters are imported from a json file, to make easier to list/document/change the variables
        that are expected to vary on each robot.
        These servo_settings are under a function, instead of root, to don't be executed when this script is used from CLI
        with arguments; In this other case the aim is to help setting the servo to their mid position."""
    
    global t_servo, t_servo_close, t_servo_open, t_servo_read, t_servo_flip, t_servo_rel, t_top_cover    # top servo related angles and status
    global t_flip_to_close_time, t_close_to_flip_time, t_flip_open_time, t_open_close_time               # top servo related timers
    global b_servo, b_servo_CCW, b_servo_CW, b_home, b_extra_sides, b_extra_home                         # bottom servo related angles
    global b_servo_CCW_rel, b_servo_CW_rel, b_home_from_CCW, b_home_from_CW                              # bottom servo related angles
    global b_servo_home, b_servo_stopped, b_servo_CW_pos, b_servo_CCW_pos                                # bottom servo related status 
    global b_spin_time, b_rotate_time, b_rel_time                                                        # bottom servo related timers 
    global robot_init_status, fun_status, led_init_status                                                # bottom servo related angles 
    
    if not robot_init_status:                                            # case the inititialization status of the servos false
        
        from getmac import get_mac_address                               # library to get the device MAC ddress
        import os.path, pathlib, json                                    # libraries needed for the json, and parameter import
        
        folder = pathlib.Path().resolve()                                # active folder (should be home/pi/cube)  
        eth_mac = get_mac_address()                                      # mac address is retrieved
        if eth_mac == 'e4:5f:01:8d:59:97':                               # case the script is running on AF (Andrea Favero) robot
            fname = os.path.join(folder,'Cubotino_T_servo_settings_AF.txt')   # AF robot settings (do not use these at the start)
        elif eth_mac == 'e4:5f:01:8b:5f:e5':                                  # case the script is running on AF (Andrea Favero) robot
            fname = os.path.join(folder,'Cubotino_T_servo_settings_AF2.txt')  # AF second robot settings (do not use these at the start)
        else:                                                            # case the script is not running on AF (Andrea Favero) robot
            fname = os.path.join(folder,'Cubotino_T_servo_settings.txt') # folder and file name for the settings, to be tuned
 
        if os.path.exists(fname):                                        # case the servo_settings file exists
            with open(fname, "r") as f:                                  # servo_settings file is opened in reading mode
                servo_settings = json.load(f)                            # json file is parsed to a local dict variable
                # NOTE: in case of git pull, the settings file will be overwritten, the backup file not
            
            backup_fname = os.path.join(folder,'Cubotino_T_servo_settings_backup.txt')     # folder and file name for the settings backup
            with open(backup_fname, 'w') as f:                           # servo_settings_backup file is opened in writing mode
                f.write(json.dumps(servo_settings, indent=0))            # content of the setting file is saved in another file, as backup
                # NOTE: in case of git pull, the settings file will be overwritten, the backup file not
            
            try:
                t_min_pulse_width = float(servo_settings['t_min_pulse_width'])        # defines the min Pulse With the top servo reacts to
                t_max_pulse_width = float(servo_settings['t_max_pulse_width'])        # defines the max Pulse With the top servo reacts to
                t_servo_close = float(servo_settings['t_servo_close'])                # Top_cover close position, in gpiozero format
                t_servo_open = float(servo_settings['t_servo_open'])                  # Top_cover open position, in gpiozero format
                t_servo_read = float(servo_settings['t_servo_read'])                  # Top_cover camera read position, in gpiozero format
                t_servo_flip = float(servo_settings['t_servo_flip'])                  # Top_cover flip position, in gpiozero format
                t_servo_rel_delta = float(servo_settings['t_servo_rel_delta'])        # Top_cover release angle movement from the close position to release tension
                t_flip_to_close_time = float(servo_settings['t_flip_to_close_time'])  # time for Top_cover from flip to close position
                t_close_to_flip_time = float(servo_settings['t_close_to_flip_time'])  # time for Top_cover from close to flip position 
                t_flip_open_time = float(servo_settings['t_flip_open_time'])          # time for Top_cover from open to flip position, and viceversa  
                t_open_close_time = float(servo_settings['t_open_close_time'])        # time for Top_cover from open to close position, and viceversa
                
                b_min_pulse_width = float(servo_settings['b_min_pulse_width'])        # defines the min Pulse With the bottom servo reacts to
                b_max_pulse_width = float(servo_settings['b_max_pulse_width'])        # defines the max Pulse With the bottom servo reacts to
                b_servo_CCW = float(servo_settings['b_servo_CCW'])                    # Cube_holder max CCW angle position
                b_servo_CW = float(servo_settings['b_servo_CW'])                      # Cube_holder max CW angle position
                b_home = float(servo_settings['b_home'])                              # Cube_holder home angle position
                b_extra_sides = float(servo_settings['b_extra_sides'])                # Cube_holder release angle from CCW and CW angle positions, to release tension
                b_extra_home = float(servo_settings['b_extra_home'])                  # Cube_holder release angle from home angle positions, to release tension
                b_spin_time = float(servo_settings['b_spin_time'])                    # time for Cube_holder to spin 90 deg (cune not contrained)
                b_rotate_time = float(servo_settings['b_rotate_time'])                # time for Cube_holder to rotate 90 deg (cube constrained)
                b_rel_time = float(servo_settings['b_rel_time'])                      # time for Cube_holder to release tension at home, CCW and CW positions
            
                
            except:   # exception will be raised if json keys differs, or parameters cannot be converted to float
                print('error on converting to float the imported parameters')   # feedback is printed to the terminal                                  
                return robot_init_status                                        # return robot_init_status variable, that is False
        
        else:                                                                   # case the servo_settings file does not exists, or name differs
            print('could not find Cubotino_T_servo_settings.txt')               # feedback is printed to the terminal                                  
            return robot_init_status                                            # return robot_init_status variable, that is False
        
        
        if not home_pos:                                                 # case the servo init is not meant to force the home positions
            # t_servo servo object creation
            t_servo = Servo(t_servo_pin,                                 # GPIO pin associated to the top servo
                            initial_value = 0,                           # Top_servo set to 0. This happens also if the initial_value parameter is omitted
                            min_pulse_width = t_min_pulse_width/1000,    # min Pulse Width the top servo reacts to
                            max_pulse_width = t_max_pulse_width/1000,    # max Pulse Width the top servo reacts to
                            pin_factory=factory)                         # way to use hardware based timers for the PWM 
            time.sleep(0.7)                                              # wait time to ensure the servo to get to 0 position
            
            # b_servo servo object creation
            b_servo = Servo(b_servo_pin,                                 # GPIO pin associated to the bottom servo
                            initial_value = 0,                           # bottomo servo set to 0. This happens also if the initial_value parameter is omitted
                            min_pulse_width = b_min_pulse_width/1000,    # min Pulse Width the bottom servo reacts to
                            max_pulse_width = b_max_pulse_width/1000,    # max Pulse Width the bottom servo reacts to
                            pin_factory=factory)                         # way to used hardware based timers for the PWM                   
            time.sleep(0.7)                                              # wait time to ensure the servo to get to 0 position

        
        elif home_pos:                                                   # case the servo init is meant to force the home positions
            # t_servo servo object creation
            t_servo = Servo(t_servo_pin,                                 # GPIO pin associated to the top servo
                            initial_value = t_servo_open,                # Top_cover positioned in open position
                            min_pulse_width = t_min_pulse_width/1000,    # min Pulse Width the top servo reacts to
                            max_pulse_width = t_max_pulse_width/1000,    # max Pulse Width the top servo reacts to
                            pin_factory=factory)                         # way to use hardware based timers for the PWM 
            time.sleep(0.7)                                              # wait time to ensure the servo to get its init position
            t_top_cover = 'open'                                         # variable to track the top cover/lifter position
        
            # b_servo servo object creation
            b_servo = Servo(b_servo_pin,                                 # GPIO pin associated to the bottom servo
                            initial_value = b_home,                      # Cube_holder positioned to home
                            min_pulse_width = b_min_pulse_width/1000,    # min Pulse Width the bottom servo reacts to
                            max_pulse_width = b_max_pulse_width/1000,    # max Pulse Width the bottom servo reacts to
                            pin_factory=factory)                         # way to used hardware based timers for the PWM                   
            time.sleep(0.7)                                              # wait time to ensure the servo to get its init position
            b_servo.value = b_home                                       # bottom servo is set to home postion at the start
            b_servo_home=True                                   # boolean of bottom servo at home
            b_servo_stopped = True                              # boolean of bottom servo at location the lifter can be operated
            b_servo_CW_pos=False                                # boolean of bottom servo at full CW position
            b_servo_CCW_pos=False                               # boolean of bottom servo at full CCW position


            # bottom servo derived positions
            b_servo_CCW_rel = b_servo_CCW + b_extra_sides       # bottom servo position to rel tensions when fully CW
            b_servo_CW_rel = b_servo_CW - b_extra_sides         # bottom servo position to rel tensions when fully CCW
            b_home_from_CW = b_home - b_extra_home              # bottom servo extra home position, when moving back from full CW
            b_home_from_CCW = b_home + b_extra_home             # bottom servo extra home position, when moving back from full CCW
            
            # top servo derived position
            t_servo_rel = t_servo_close - t_servo_rel_delta     # top servo position to release tension

            robot_init_status = True          # boolean to track the inititialization status of the servos is set true
            if print_out:
                print("servo init done")
        
        
            servo_start_pos()                 # servos are positioned to the start position    
            fun_status=False                  # boolean to track the robot fun status, it is True after solving the cube :-)
            servo_off()                       # PWM signal at GPIO is stopped
            cam_led_test()                    # makes a very short led test
            cam_led_Off()                     # forces the led off
    
    return robot_init_status







def quit_func():
    """ Sets the used GPIO as output, and force them to low. This wants to prevent servos to move after closing the script."""
    
    GPIO.setup(top_cover_led_pin, GPIO.OUT, initial=GPIO.LOW)   # GPIO top_cover_led_pin (Top_cover_Led) is set as output, and force low
    GPIO.setup(t_servo_pin, GPIO.OUT, initial=GPIO.LOW)         # GPIO t_servo_pin (Top_cover servo) is set as output, and force low
    GPIO.setup(b_servo_pin, GPIO.OUT, initial=GPIO.LOW)         # GPIO b_servo_pin (Cube_holder servo) is set as output, and force low







def cam_led_On(value=0.05):
    """ Sets the top_cover led ON, with brightness in arg. Value ranges from 0 to 0.3"""
    
    if value >= 0.3:                              # case arg is bigger than, or equal to 0.3
        top_cover_led.value = 0.3                 # top cover led PWM is set to 30%
    else:                                         # case arg is smaller than 0.3
        top_cover_led.value = value               # top cover led PWM is set to arg value






def cam_led_Off():
    """ Sets the top_cover led OFF."""
    
    top_cover_led.off()      # top cover led PWM is set to 0







def cam_led_test():
    """ Fade the led On and Off at the init, to show the led worwing."""
    
    for i in range(0,32,4):            # iterates from 0 to 28 in steps of 4 
        top_cover_led.value = i/100    # top cover led PWM is set iterator %
        time.sleep(0.02)               # very short time sleep
    
    for i in range(28,-4,-4):          # iterates from 28 to 0 in steps of -4 
        top_cover_led.value = i/100    # top cover led PWM is set iterator %
        time.sleep(0.02)               # very short time sleep






def servo_start_pos():
    """Servos are positioned to the intended start position, meaning top_cover on read position and cube_holder on its middle position"""
    
    global t_servo_open, t_top_cover
    global b_servo_operable, b_servo_stopped,  b_servo_home, b_servo_CW_pos, b_servo_CCW_pos
    global stop_servos
    
    stop_servos=False                 # boolean to stop the servos during solving process is set False: servos can be operated
    b_servo_operable=False            # variable to block/allow bottom servo operation
    
    
    t_servo.value = t_servo_open      # top servo is positioned in open position
    time.sleep(t_close_to_flip_time)  # time to allow the top_cover/lifter to reach the open postion   
    t_top_cover = 'open'              # variable to track the top cover/lifter position
    b_servo_operable=True             # variable to block/allow bottom servo operation
    
    
    b_servo.value = b_home            # bottom servo moves to the home position, releasing then the tensions
    time.sleep(b_rotate_time)         # time for the servo to release the tensions
    
    b_servo_stopped = True            # boolean of bottom servo at location the lifter can be operated
    b_servo_home=True                 # boolean of bottom servo at home
    b_servo_CW_pos=False              # boolean of bottom servo at full CW position
    b_servo_CCW_pos=False             # boolean of bottom servo at full CCW position
    
    b_servo_operable=False            # variable to block/allow bottom servo operation
    t_servo.value = t_servo_read      # top servo is positioned in read position at the start
    time.sleep(t_flip_open_time)      # time to allow the top_cover/lifter to reach the read postion
    t_top_cover = 'read'              # variable to track the top cover/lifter position
    
    cam_led_Off()                     # forces the top_cover_led to off






def servo_off():
    """ Function to stop sending the PWM the servos."""
    
#     t_servo.detach()             # PWM is stopped at the GPIO pin for top servo
#     b_servo.detach()             # PWM is stopped at the GPIO pin for bottom servo
    return







def stopping_servos(print_out=s_debug):
    """ Function to stop the servos."""
    global stop_servos
    
    if print_out:
        print("\ncalled the servos stopping function\n")    
    stop_servos=True                      # boolean to stop the servos during solving process, is set true: Servos are stopped







def stop_release(print_out=s_debug):
    """ Function to relelease the stop from servos."""
    
    global stop_servos
    
    if print_out:
        print("\ncalled the stop release function\n")
    stop_servos=False            # boolean to stop the servos during solving process, is set false: Servo can be operated
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

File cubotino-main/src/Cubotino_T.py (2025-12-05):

#!/usr/bin/python
# coding: utf-8

def import_parameters():
    """ Function to import parameters from a json file, to make easier to list/document/change the variables
        that are expected to vary on each robot."""
       
    global frameless_cube, camera_width_res, camera_hight_res
    global kl, x_l, x_r, y_u, y_b, warp_fraction, warp_slicing, square_ratio, rhombus_ratio
    global delta_area_limit, sv_max_moves, sv_max_time, collage_w, marg_coef, cam_led_bright
    global detect_timeout, show_time, warn_time, quit_time, cover_self_close
    global pathlib
    
    import os.path, pathlib, json                                 # libraries needed for the json, and parameter import
    from getmac import get_mac_address                            # library to get the device MAC ddress
        
    folder = pathlib.Path().resolve()                             # active folder (should be home/pi/cube)  
    eth_mac = get_mac_address()                                   # mac address is retrieved
    if eth_mac == 'e4:5f:01:8d:59:97':                            # case the script is running on MaC
        fname = os.path.join(folder,'Cubotino_T_settings_AF.txt') # AF robot settings (do not use these at the start)
    elif eth_mac == 'e4:5f:01:8b:5f:e5':                          # case the script is running on Mac
        fname = os.path.join(folder,'Cubotino_T_settings_AF2.txt')# AF second robot settings (do not use these at the start)
    else:                                                         # case the script is not running on AF robot
        fname = os.path.join(folder,'Cubotino_T_settings.txt')    # folder and file name for the settings, to be tuned
    
    if os.path.exists(fname):                                     # case the settings file exists
        with open(fname, "r") as f:                               # settings file is opened in reading mode
            settings = json.load(f)                               # json file is parsed to a local dict variable
            # NOTE: in case of git pull, the settings file will be overwritten, the backup file not
        
        if debug:                                                 # case debug variable is set true on __main_
            print('\nimporting settings from the text file:', fname)    # feedback is printed to the termina
            print('\nimported parameters: ')                      # feedback is printed to the terminal
            for parameter, setting in settings.items():           # iteration over the settings dict
                print(parameter,': ', setting)                    # feedback is printed to the terminal
            print()
            
        os.umask(0) # The default umask is 0o22 which turns off write permission of group and others
        backup_fname = os.path.join(folder,'Cubotino_T_settings_backup.txt')          # folder and file name for the settings backup
        with open(os.open(backup_fname, os.O_CREAT | os.O_WRONLY, 0o777), 'w') as f:  # settings_backup file is opened in writing mode
            if debug:                                             # case debug variable is set true on __main_
                print('copy of settings parameter is saved as backup at: ', backup_fname)    # feedback is printed to the terminal
            f.write(json.dumps(settings, indent=0))               # content of the setting file is saved in another file, as backup
            # NOTE: in case of git pull, the settings file will be overwritten, the backup file not
        
        if debug:                                                 # case debug variable is set true on __main_
            print('\nimported parameters are saved to the backup file\n') # feedback is printed to the terminal
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
